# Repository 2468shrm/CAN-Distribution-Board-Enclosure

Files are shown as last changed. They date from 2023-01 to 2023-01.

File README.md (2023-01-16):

# CAN-Distribution-Board-Enclosure

This repo inclues the design for a 3D-printable enclosure for the
CAN-Distribution-With-Debug and CAN-Distribution-Board-With-Power-v2 PCBs
to make mounting easier on FRC robots.

The enclosure for a board is assembled from 2 or 3 3D printed parts:
- Bottom - Always needed, it goes below the PCB
- Top - Always needed (or Top for Debug), it goes above the PCB.  There are a couple of
options for tops available, one should be selected and used.
  - (Normal) Top - includes openings for termination headers.
This is used when enclosing the CAN-Distribution-Board-With-Power-v2 PCB.
  - Low profile Top - does not include an opening for termination headers and is a lower
profile (less height) enclosure. This is used when enclosing the
CAN-Distribution-Board-With-Power-v2 PCB.
  - Top for debug - includes openings for debug elements and termination headers.
This is used when enclosing the CAN-Distribution-With-Debug PCB.
- Termination Top - An optional item for Tops that expose a pair of headers for CAN
termination.  The Termination Top is used to cover/block the termination header opening
in the Top. Needed only if the termination headers are installed but not used
and the opening is to be blocked.

The Bottom and Top are screwed together using M2 hardware.  The enclosure is connected
to the robot using 8-32 screws.

As assembled, the enclosure is as follows:

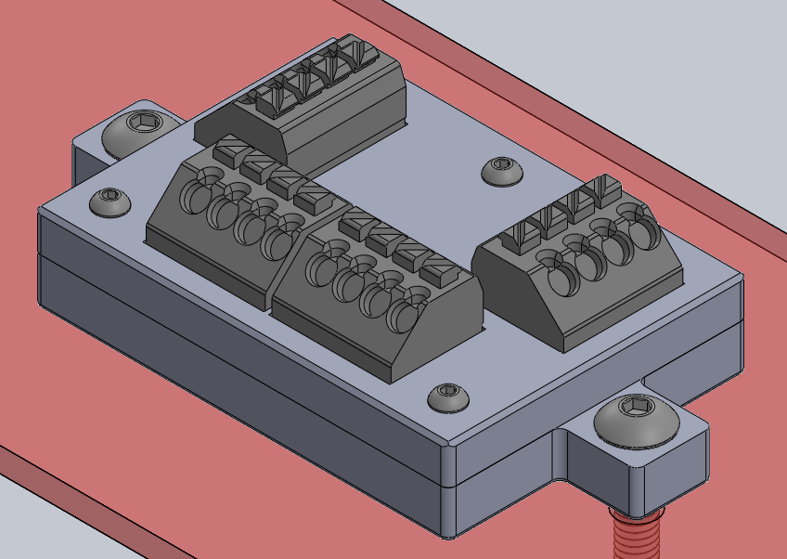
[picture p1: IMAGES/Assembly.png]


Note: This is with Top (no debug features populated on the board) and the Termination Top
is installed.

## Bottom

A very simple base/bottom of the enclosure.  The bottom requires you to press in 3
heat set inserts.

The bottom uses 3 M2 heat set inserts to connect with screws from the top to hold the
two halfs together.
- McMaster [94180A307](https://www.mcmaster.com/catalog/94180A307)

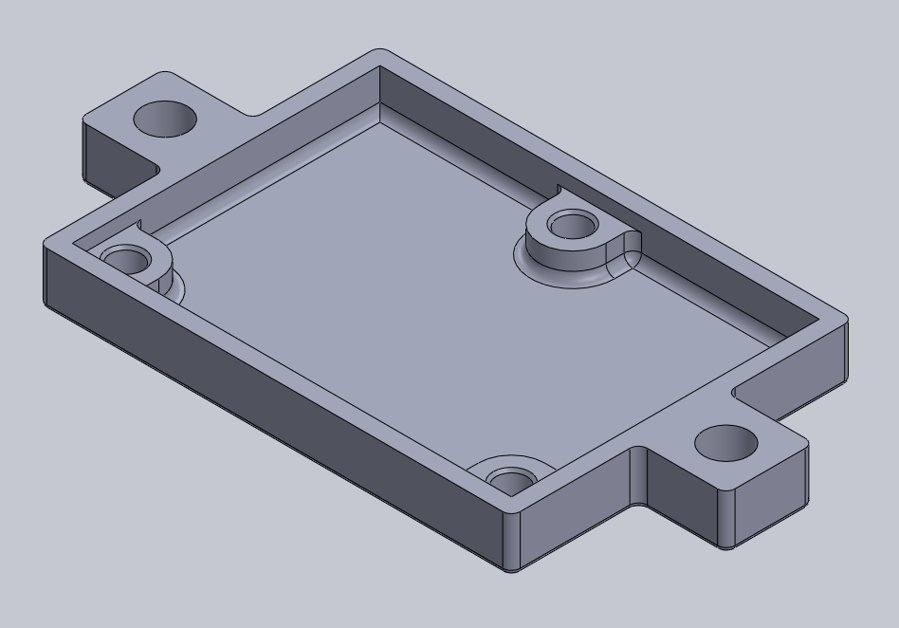
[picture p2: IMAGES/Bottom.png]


## (Normal) Top

A very simple top of the enclosure. The termination header window is included. To block it,
use the Termination Top.

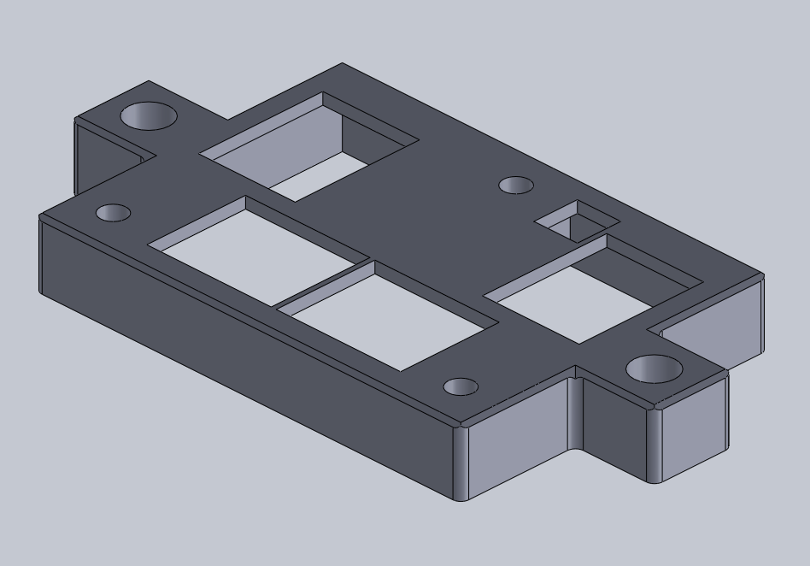
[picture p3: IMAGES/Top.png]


## Low Profile Top (No Termination or Debug windows)

A low-profile (low height) top for the enclosure. It is the preferred version for 2468 in
FRC applications as it should minimize debris/swarf from entering the enclosure.

This top allows the enclosure to be assembled with a 10 mm M2 screw.
- McMaster [92095A104](https://www.mcmaster.com/catalog/92095A104)

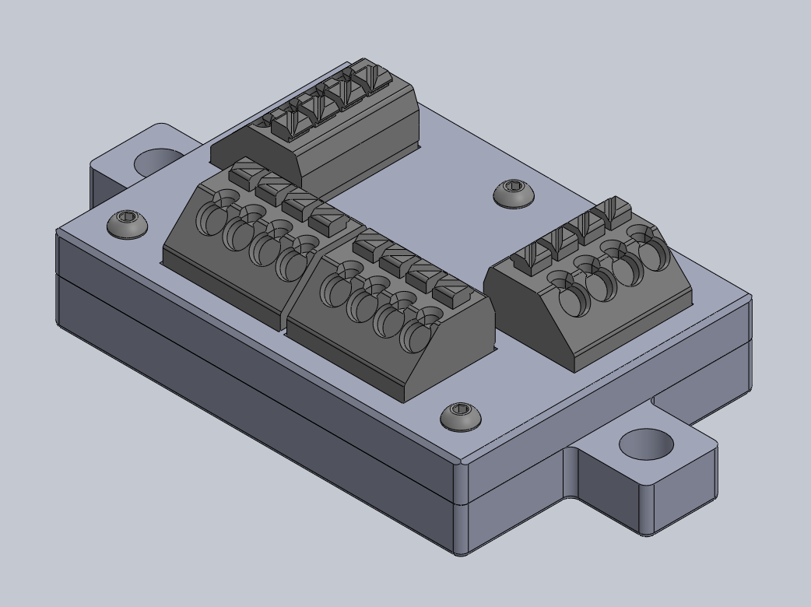
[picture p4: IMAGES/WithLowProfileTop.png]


## Top for Debug

The same as Top, but with windows for debug hardware (power block and a light pipe to
transmit the LED to the top.

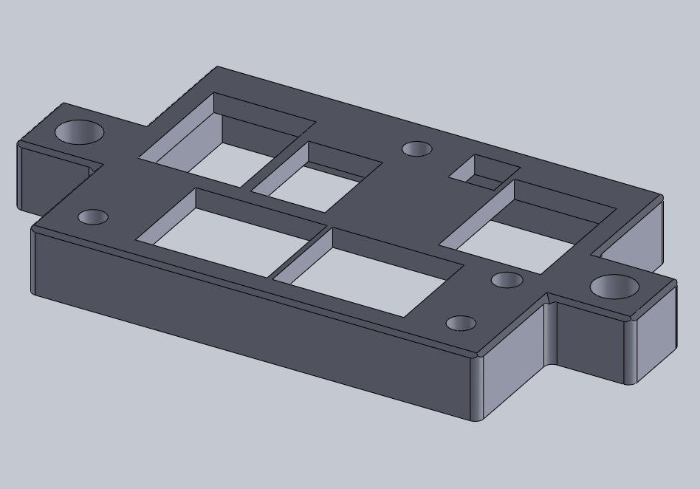
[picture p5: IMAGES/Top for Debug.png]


## Termination Top

The termination top is used for Tops (normal and debug) when the termination headers should
be covered to avoid debrus/swarf from entering the enclosure.  The Termination Top is
expected to be glued to the top (e.g. super glue).

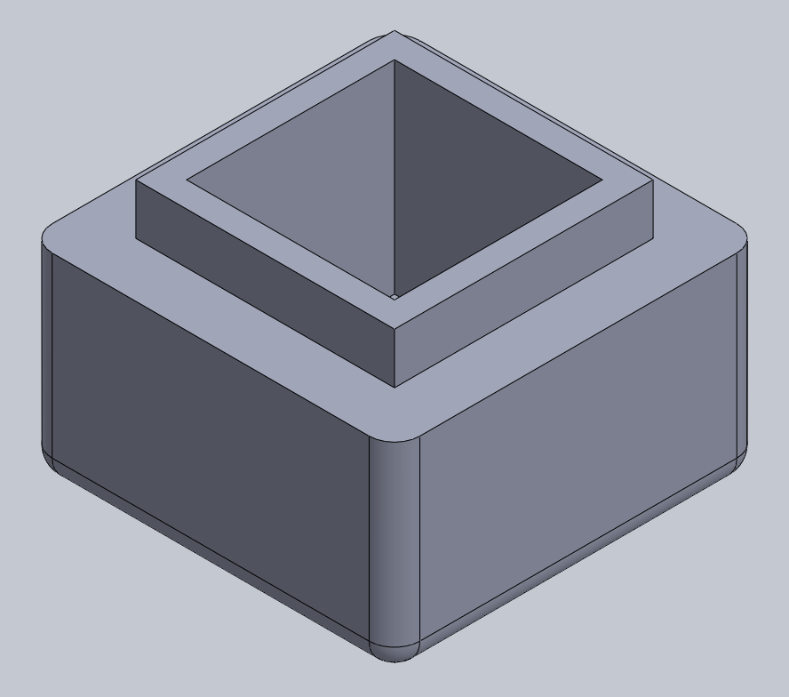
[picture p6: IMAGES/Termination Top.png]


# Identification and Association of the Connectors and Signals

To avoid mistakes in robot wiring, it is recommended that the connectors be identified
similarly to the REV, NI and CTRE hardware.  NI and CTRE uses Weidmuller connectors
and they typically identify CAN connections on the enclosure of the product.  REV gets
WAGO connectors pre-colored by the factory.

## Identification Conventions

The standard used by the existing CAN-device vendors use one of two methods.  CAN wire is
universally a twisted pair of yellow/green wire ().  The yellow is CAN_H and the green
is CAN_L.  If color is not used connectors are labeled H and L (in some cases both color 
and letter are both used).

At 2468, to remember which is which, we say "the yellow sun is High in the sky, but the
green grass is Low in the ground."

## Identifying Connections on the CAN Distribution Board

We have found that medium tipped Sharpie pens are useful for coloring the WAGO 250-series
connectors.  We normally color the plastic below the opening for the wire down to the PCB.
Coloring is straight forward because the connector is stacked up and seams exist between
inputs, providing "lines" to color within.

This image shows two enclosures, one with attached low-profile top and one without top. Both
include connectors colored with sharpies to indicate the purpose of each connection.
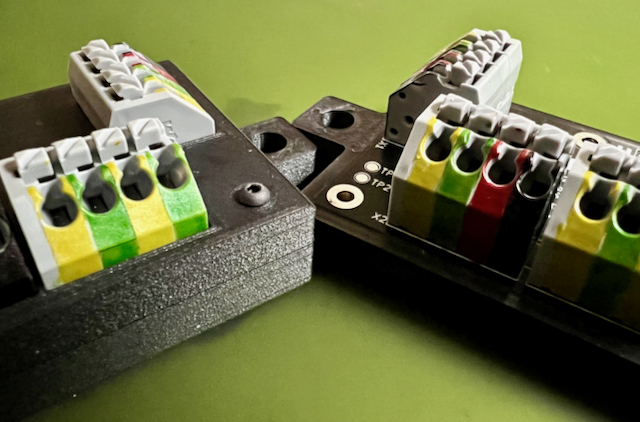
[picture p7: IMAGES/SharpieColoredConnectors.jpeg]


We are also experimenting with the use of laser-printed decals. The decal paper is
purchased from Amazon and craft stores. Each CAN Distribution Board requires a set of
four decals, one per WAGO 250-204 connector. We believe the decal can be applied to
the connector in the same region as the sharpie color in, however we will also experiment
with adding a decal on the enclosure plastic (top) in front of the WAGO connector.

The set is shown below, but
[PDF](https://github.com/2468shrm/CAN-Distribution-Board-Enclosure/blob/main/Decals/CAN%20Distribution%20Board%20Decals.pdf)
and [SVF](https://github.com/2468shrm/CAN-Distribution-Board-Enclosure/blob/main/Decals/CAN%20Distribution%20Board%20Decals.svg)
files containing a large number of sets is available in the repository. The SVG is provided
should you wish to modify the decal patter (we use Inkscape). The PDF is provided for
the simplest path to printing.

Reminder: The decal approach is currently under development by 2468. At present we use
sharpies, but would prefer the "professional" look of decals in the future. We share the
information preliminarily.



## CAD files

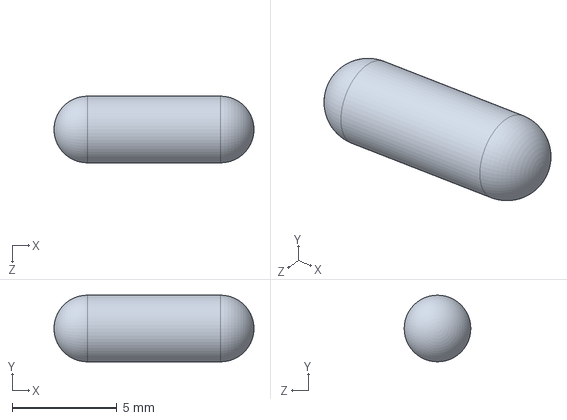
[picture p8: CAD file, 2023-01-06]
Light Pipe.SLDPRT
9.53 x 3.17 x 3.17 mm

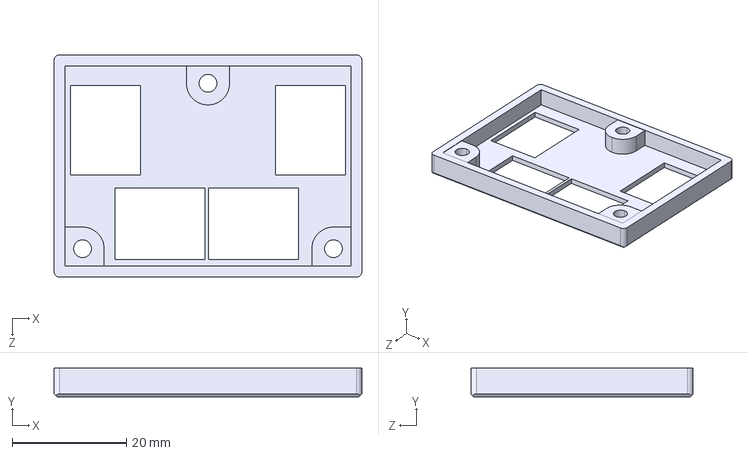
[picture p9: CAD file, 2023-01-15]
STEP/Top No Termination Low Profile.STEP
54.0 x 5.00 x 39.0 mm

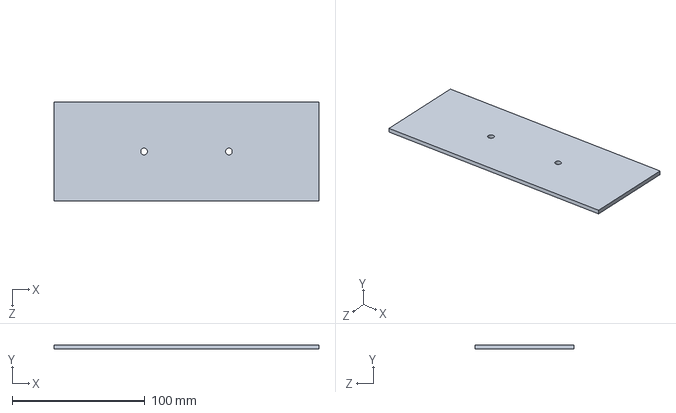
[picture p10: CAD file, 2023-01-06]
Assembly Support Parts/Belly Pan Simulation.SLDPRT
200.0 x 3.17 x 75.0 mm

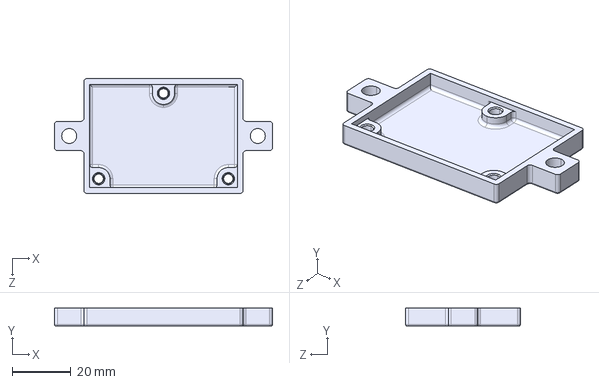
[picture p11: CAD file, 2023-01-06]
STEP/Bottom.STEP
74.0 x 6.10 x 39.0 mm

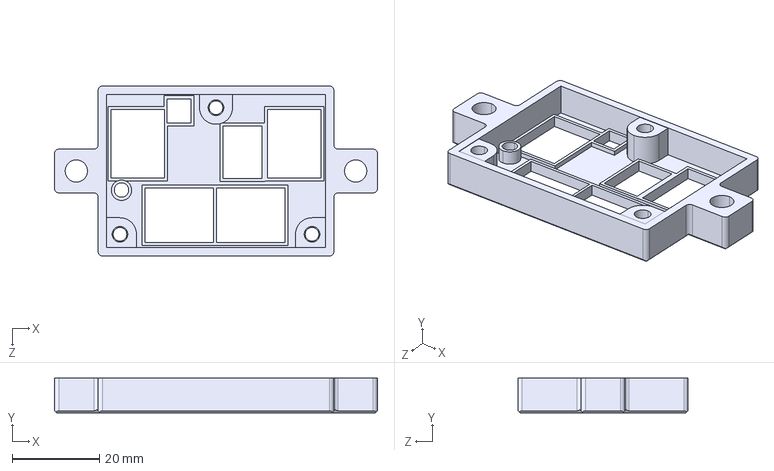
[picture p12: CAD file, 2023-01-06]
STEP/Top for Debug.STEP
74.0 x 8.00 x 39.0 mm

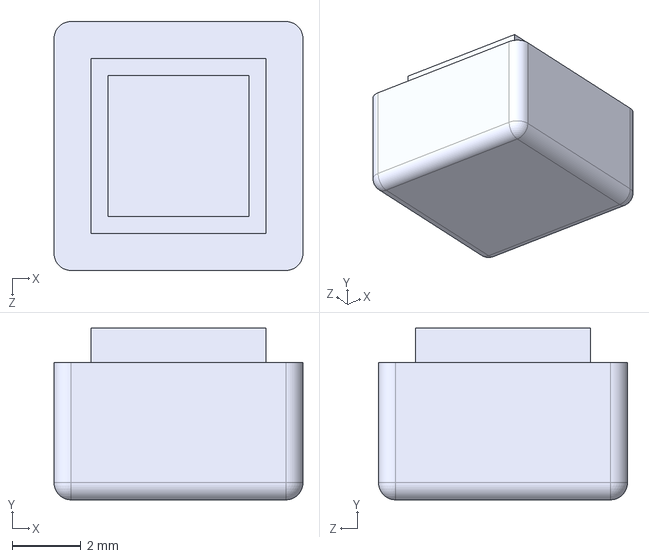
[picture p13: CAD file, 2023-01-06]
STEP/Termination Top.STEP
7.25 x 5.00 x 7.25 mm

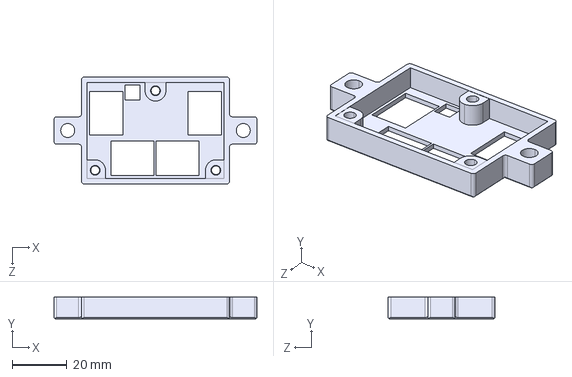
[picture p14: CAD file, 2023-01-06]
STEP/Top.STEP
74.0 x 8.00 x 39.0 mm

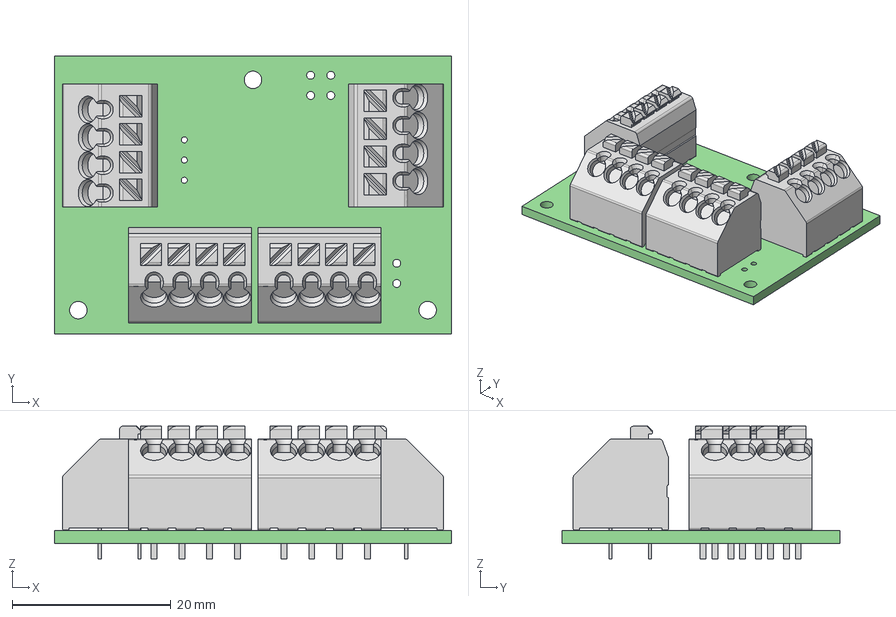
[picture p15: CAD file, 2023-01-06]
STEP/CAN Distribution With Debug.step
50.0 x 35.0 x 16.7 mm
CAN Distribution With Debug PCB

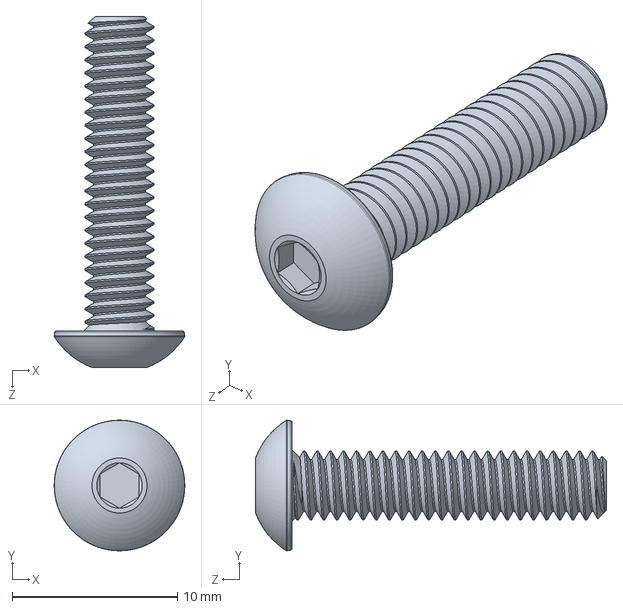
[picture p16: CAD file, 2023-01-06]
Assembly Support Parts/91255A197_Button Head Hex Drive Screw.SLDPRT
7.91 x 7.91 x 21.3 mm

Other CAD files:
Bottom.SLDPRT
CAN Distribution With Debug.SLDASM
STL/Bottom.STL
STL/Termination Top.STL
STL/Top No Termination Low Profile.STL
STL/Top for Debug.STL
STL/Top.STL
Termination Top.SLDPRT
Top No Termination Low Profile.SLDPRT
Top for Debug.SLDPRT
Top.SLDPRT

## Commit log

2023-01-06 initial commit of files
    [91255A197_Button Head Hex Drive Screw.SLDPRT, Belly Pan Simulation.SLDPRT, Bottom.SLDPRT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]
2023-01-15 adding a low profile top.. removed tabs and lower height
    [Top No Termination Low Profile.STEP, Top No Termination Low Profile.STL]
2023-01-15 SolidWorks file for added low-profile top
    [Top No Termination Low Profile.SLDPRT]
2023-01-16 adding sharpie-colored enclosure image
